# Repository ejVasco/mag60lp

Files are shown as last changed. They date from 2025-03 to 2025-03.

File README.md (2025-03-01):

# mag60lp
WIP 60&amp; low profile keyboard with the goal of easy compact storage hopefully via some magnetic attachment system. 

## Progress Report:
| |Task | Status | Notes |
|-|-|-|-
|Designing| Layout | Researching | 60% Split
| | PCB | In Progress | Split 
| | Plate | Researching | 
| | Case | Not started | seems simple enough except for the magnetic mechanism I want
| | Plate and PCB mounting mechanism | Not Started | Gasket seems really popular nowadays
| | Bill of parts | Not Started | screws, heat inserted standoffs, magnets, diodes, microcontrollers, trrs connectors, etc.
| Choose | Switches | Not Started | Low Profile Kailh Choc V2 Switches
| | Plate Material | Not Started | Want Quiet
| | Case Material | Not Started | Want Quiet and possible transparent
| | Case Foam | Not Started | Optional, but not if transparent case
| | Microcontroller | Researching | Between Pro Micro and Elite C
| | Other hardware (TRRS, CapsLock LED, possible OLED screen, diodes) | Not Started | Connect the two halves
| | Stabilizers | Not Started | ... do low profile have stabs?
| | Keycaps | Not Started | Is it possible to get stepped capslock? also want something uniform or blank so I don't have to look at qwerty and also so I only have a single height to think about while designing the case closing mechanism, better be some nice double shot if it has legends on it.
| | Button for reset switch for flashing firmware easier | Not Started | Just to make it easier if anyone actually builds this.
| | Cables | Not Started | Keep in mind cable length and maybe color match or something.
| Assemble | Lube switches | Not Started | ... can you lube low profile switches?
| | Diodes on PCB | Not Started | probably test too
| | put more soldering tasks here later
| | Heat inserted threads/standoffs for the case | Not Started
| Program | Basic Firmware | Not Started | lowkey scared
| | Via Compatability | Not Started | Desperately want
# Cache refresh

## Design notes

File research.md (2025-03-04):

# Research Document for mag60lp
My main inspiration for this project is my want for a nice portable keybard that I can take everywhere, that will hopefully last years to come.
## Required Wants
- 60% keyboard, at this point I have realized I don't use the F row keys or numpad, or arrow keys much (and these keys can be on a layer under if i need them.)
- Split keyboard
- Via support
- Low profile (maybe make a normal profile in the future, but current focus is on portability)
- Stores in a way that keys are not exposed
- Quiet (put in required b/c should be easy enough)
- PCB not hand wired, mainly for the experience of designing a pcb
- Probably going to go with soldered switches for longer term reliability
### Hopeful Wants
- Clear/Translucent Case (Either smokey black or smokey pruple, but clear is fine)
- Foam to be quieter but only if the case is opaque
- Caps-lock light (maybe num-lock and scroll-lock too)
    - Or even better an OLED screen (however, I'm hesitant to add potentially fragile components)
- The storage mechanism uses magnets to  lock in place
- physical switch that can change layers
### No longer want
- Ortholinear (decided against b/c I want something more familiar for my first, but I'll consider it in the future)
## What I need to do
I'm currently working on this and decided that I will move this to the [README.md](./README.md), so the tasks and status's here will no longer recieve updates.
| |Task | Status | Notes |
|-|-|-|-
|Designing| Layout | Researching | 60% Split
| | PCB | Researching | Split 
| | Plate | Researching | 
| | Case | Not started | seems simple enough except for the magnetic mechanism I want
| | Plate and PCB mounting mechanism | Not Started | Gasket seems really popular nowadays
| | Bill of parts | Not Started | screws, heat inserted standoffs, magnets, diodes, microcontrollers, trrs connectors, etc.
| Choose | Switches | Not Started | Low Profile Kailh Choc V2 Switches
| | Plate Material | Not Started | Want Quiet
| | Case Material | Not Started | Want Quiet and possible transparent
| | Case Foam | Not Started | Optional, but not if transparent case
| | Microcontroller | Researching | Between Pro Micro and Elite C
| | Other hardware (TRRS, CapsLock LED, possible OLED screen, diodes) | Not Started | Connect the two halves
| | Stabilizers | Not Started | ... do low profile have stabs?
| | Keycaps | Not Started | Is it possible to get stepped capslock? also want something uniform or blank so I don't have to look at qwerty and also so I only have a single height to think about while designing the case closing mechanism, better be some nice double shot if it has legends on it.
| | Button for reset switch for flashing firmware easier | Not Started | Just to make it easier if anyone actually builds this.
| | Cables | Not Started | Keep in mind cable length and maybe color match or something.
| Assemble | Lube switches | Not Started | ... can you lube low profile switches?
| | Diodes on PCB | Not Started | probably test too
| | put more soldering tasks here later
| | Heat inserted threads/standoffs for the case | Not Started
| Program | Basic Firmware | Not Started | lowkey scared
| | Via Compatability | Not Started | Desperately want
## Software to Accomplish this
- KiCad
    - Common for open source keyboard designing but not the most beginner friendly
    - support for kailh choc v2 switch footprint
- erogen
    - can be used alongside KiCad
    - generate layouts, and define layouts via YAML file

## Resources Used
### Joe Scotto has a video on designing the PCB in kicad
https://youtu.be/8WXpGTIbxlQ?si=De-9pDI-k79aXWpj
- in the video he has a compilation of libraries for kicad
    - https://github.com/joe-scotto/scottokeebs/tree/main/Extras/ScottoKicad
    - this is nice because it includes parts for keyboards so I don't have to create them myself (switches, oled, microcontrollers, trrsr etc) 
### KiCad defaults
My defaults for KiCad were missing so I ran the following
``` bash
git clone https://gitlab.com/kicad/libraries/kicad-symbols.git
git clone https://gitlab.com/kicad/libraries/kicad-footprints.git
git clone https://gitlab.com/kicad/libraries/kicad-packages3D.git
```
# Major revalations realized while progressing.
### Differences between kaihl choc v1 and choc v2, Mar01.2025
- for choc v1 you space them 18mm horizontally and 17mm vertically and they keycaps for these switches match this specification
- for choc v2 you use standard mx spacing 19.05mm and these switches are compatible with mx caps, so you just choose a key cap profile that is flat and low
- I stood up till 2 AM last night doing spacing for choc v1 when i specifically want v2
- I literally just bought a low profile keyboard (still shipping) that uses choc v2 so I was confused on the different spacing and keycap stuff
#### Mar02.2025 Update
- looking into switches more it seems that looking at nuphy keyboards was a confusing mistake
    - they seem to be using proprietary switches on most of their low profile keebs
    - the kick75 uses nano switches witch are the same footprint as mx style switches it seems?
- I'm gonna pause anymore designing until i research more and decide for certain what switches i want to use
#### Mar04.2025 Update
- I have made somewhat of a decision... I'm gonna try at least 3 kinds of switches on the keeb
    - sunset tactile choc switches from lowprokb (choc v1)
        - https://lowprokb.ca/collections/switches/products/sunset-tactile-choc-switches
    - ambients silent choc switches from lowprokb (preferably the sunrise tactile if i can get em) (choc v1)
        - https://lowprokb.ca/collections/switches/products/ambients-silent-choc-switches?variant=44873446391972
    - kailh deep sea silent min low profile keyboard switch (choc v2)
        - https://kailhswitch.net/products/kailh-deep-sea-silent-min-low-profile-keyboard-switch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
### Typing angle
- recently i built a numpad and its very uncomfortable to use, and i drew the conclusion that is because its perfectly flat.
as a result i definietly want to have some sort of typing angle integratted in my design

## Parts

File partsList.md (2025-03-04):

# Parts List
A list of my final hardware for this kit, may update with different configurations on demain.
## WIP List
| Component | Specific | Note |
|-|-|-
| Switch | Sunset Tactile, Ambient Silent, Deep Sea Silent
| PCB | WIP

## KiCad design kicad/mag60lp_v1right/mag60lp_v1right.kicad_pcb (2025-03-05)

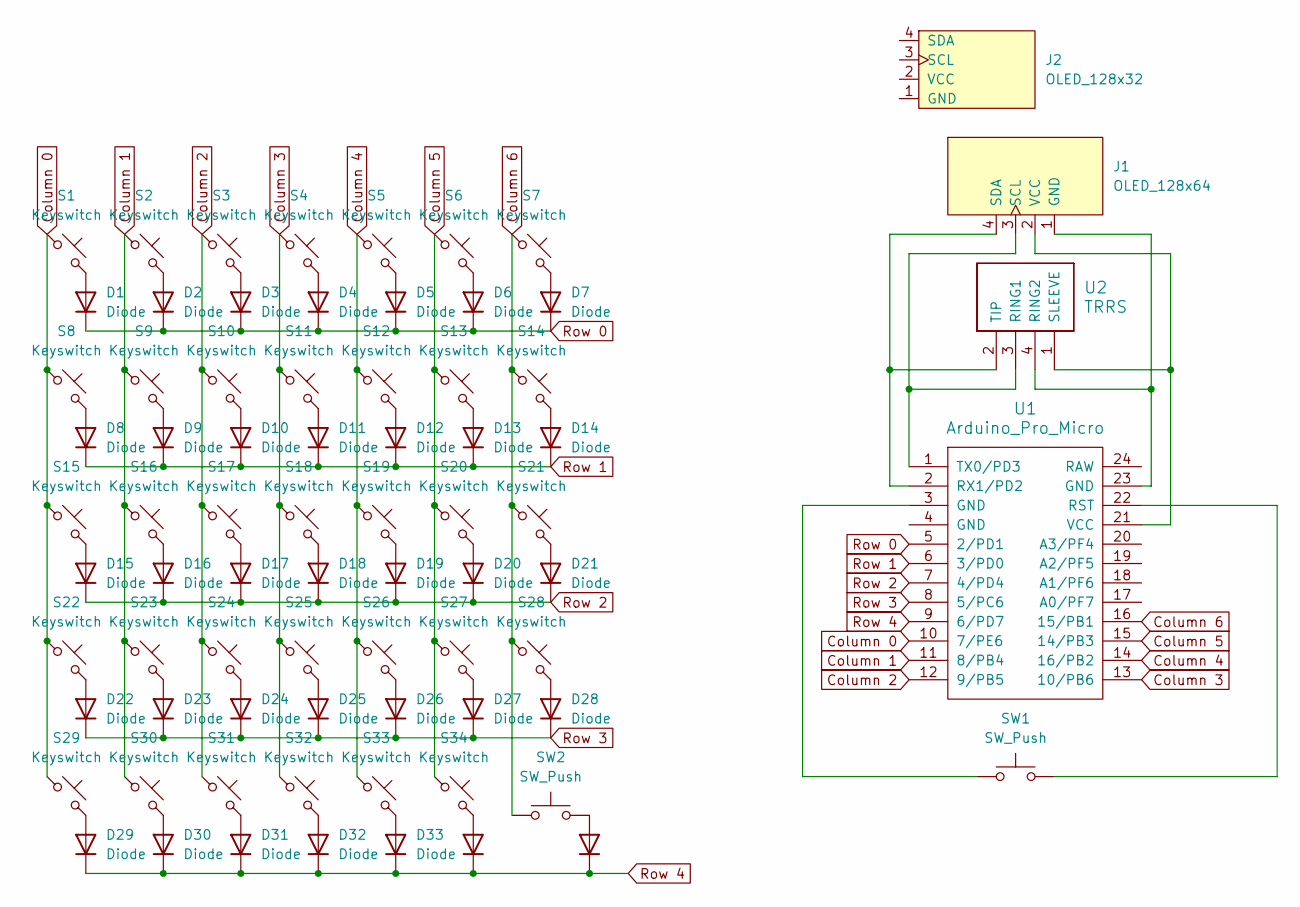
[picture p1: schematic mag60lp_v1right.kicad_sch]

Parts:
D1, D2, D3, D4, D5, D6, D7, D8, D9, D10, D11, D12, D13, D14, D15, D16, D17, D18, D19, D20, D21, D22, D23, D24, D25, D26, D27, D28, D29, D30, D31, D32, D33, D34, D35: Diode; Diode_DO-35
J1: OLED_128x64
J2: OLED_128x32
S1, S2, S3, S4, S5, S6, S7, S8, S9, S10, S11, S12, S13, S14, S15, S16, S17, S18, S19, S20, S22, S23, S24, S25, S26: Keyswitch; Choc_V1V2_1.00u
S21: Keyswitch; Choc_V1V2_2.00u
S27, S29: Keyswitch; Choc_V1V2_2.75u
S28: Keyswitch; Choc_V1V2_1.50u
S30, S31, S32, S33, S34: Keyswitch; Choc_V1V2_1.25u
SW1, SW2: SW_Push; SW_PUSH_6mm_H4.3mm
U1: Arduino_Pro_Micro
U2: TRRS; TRRS_PJ-320A

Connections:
Column 0: S1.1, S8.1, S15.1, S22.1, S29.1, U1.10 (7/PE6)
Column 1: S2.1, S9.1, S16.1, S23.1, S30.1, U1.11 (8/PB4)
Column 2: S3.1, S10.1, S17.1, S24.1, S31.1, U1.12 (9/PB5)
Column 3: S4.1, S11.1, S18.1, S25.1, S32.1, U1.13 (10/PB6)
Column 4: S5.1, S12.1, S19.1, S26.1, S33.1, U1.14 (16/PB2)
Column 5: S6.1, S13.1, S20.1, S27.1, S34.1, U1.15 (14/PB3)
Column 6: S7.1, S14.1, S21.1, S28.1, SW2.1, U1.16 (15/PB1)
unnamed: D1.2 (A), S1.2
unnamed: D2.2 (A), S2.2
unnamed: D3.2 (A), S3.2
unnamed: D4.2 (A), S4.2
unnamed: D5.2 (A), S5.2
unnamed: D6.2 (A), S6.2
unnamed: D7.2 (A), S7.2
unnamed: D8.2 (A), S8.2
unnamed: D9.2 (A), S9.2
unnamed: D10.2 (A), S10.2
unnamed: D11.2 (A), S11.2
unnamed: D12.2 (A), S12.2
unnamed: D13.2 (A), S13.2
unnamed: D14.2 (A), S14.2
unnamed: D15.2 (A), S15.2
unnamed: D16.2 (A), S16.2
unnamed: D17.2 (A), S17.2
unnamed: D18.2 (A), S18.2
unnamed: D19.2 (A), S19.2
unnamed: D20.2 (A), S20.2
unnamed: D21.2 (A), S21.2
unnamed: D22.2 (A), S22.2
unnamed: D23.2 (A), S23.2
unnamed: D24.2 (A), S24.2
unnamed: D25.2 (A), S25.2
unnamed: D26.2 (A), S26.2
unnamed: D27.2 (A), S27.2
unnamed: D28.2 (A), S28.2
unnamed: D29.2 (A), S29.2
unnamed: D30.2 (A), S30.2
unnamed: D31.2 (A), S31.2
unnamed: D32.2 (A), S32.2
unnamed: D33.2 (A), S33.2
unnamed: D34.2 (A), S34.2
unnamed: D35.2 (A), SW2.2
unnamed: J1.1 (GND), U1.23 (GND), U2.4 (RING2)
unnamed: J1.3 (SCL), U1.1 (TX0/PD3), U2.3 (RING1)
unnamed: J1.4 (SDA), U1.2 (RX1/PD2), U2.2 (TIP)
unnamed: J1.2 (VCC), U1.21 (VCC), U2.1 (SLEEVE)
unnamed: SW1.1, U1.3 (GND)
unnamed: SW1.2, U1.22 (RST)
Row 0: D1.1 (K), D2.1 (K), D3.1 (K), D4.1 (K), D5.1 (K), D6.1 (K), D7.1 (K), U1.5 (2/PD1)
Row 1: D8.1 (K), D9.1 (K), D10.1 (K), D11.1 (K), D12.1 (K), D13.1 (K), D14.1 (K), U1.6 (3/PD0)
Row 2: D15.1 (K), D16.1 (K), D17.1 (K), D18.1 (K), D19.1 (K), D20.1 (K), D21.1 (K), U1.7 (4/PD4)
Row 3: D22.1 (K), D23.1 (K), D24.1 (K), D25.1 (K), D26.1 (K), D27.1 (K), D28.1 (K), U1.8 (5/PC6)
Row 4: D29.1 (K), D30.1 (K), D31.1 (K), D32.1 (K), D33.1 (K), D34.1 (K), D35.1 (K), U1.9 (6/PD7)

Board: 2 copper layers, 75 parts (35 on the bottom side), 53 nets, no tracks yet.

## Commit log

2025-03-01 re-uped the repo
    [mag60lp_v1left.kicad_pcb, mag60lp_v1left.kicad_sch]
2025-03-01 worked on pcb designs
    [mag60lp_v1right.kicad_pcb, mag60lp_v1right.kicad_sch]
2025-03-01 deleted uneccesary kicad file
2025-03-01 attempt to ignore backup for kicad
2025-03-01 updated pcb design status to in progress
2025-03-02 worked on cpb, but im still so confused
    [mag60lp_v1right.kicad_pcb, mag60lp_v1right.kicad_sch]
2025-03-02 pausing design untill i can figure out which switches for certain i want to use
    see
    #### Mar02.2025 Update for details
2025-03-03 halfway through pcb
    [mag60lp_v1right.kicad_pcb]
2025-03-03 pcb done?
    i cant rember rn, i did this last night
    [mag60lp_v1right.kicad_pcb, mag60lp_v1right.kicad_sch]
2025-03-04 finalized switches to try
2025-03-05 im losing my mind working on this
    [mag60lp_v1right.kicad_pcb, mag60lp_v1right.kicad_sch]
2025-03-05 layout im going for added temporarily
    [templayout.ods]
